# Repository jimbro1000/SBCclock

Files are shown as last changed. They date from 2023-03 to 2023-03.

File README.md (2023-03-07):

# Clock Card for HD6309SBC #

This board provides a variety of divided clock signals
to the 6809SBC board.

Where the SBC board calls for a quadrature clock (for
the 6809E variants) the board also provides Q and E.

The design is intended to be swappable to permit
easy exchange of different clock rates or different
clock generator designs.

The intended target is a raw clock of 25.175MHz to
facilitate a VGA signal. The CPU then operates at
one eighth of that - 3.15MHz, slightly above the
expected clock maximum for a C-class processor but
well within tolerance.

By having a swappable clock card the target 
operating frequency can be halved again to allow
the use of B-class processors while retaining
the 25MHz VGA signal. Again this is slightly
above specification at 1.57MHz but within the
tolerance of the design.

## Outputs ##

The card must provide the raw clock on Clock24, this
can be any frequency (that the CPUs support) but 
changing from the VGA clock frequency will require a
different approach to video output.

Outputs are then expected for the clock divided by
2, 4, 8 and 16 (Clock12, Clock6, Clock3 and Clock1.5)

Where Q and E are used they are output along with the
inverse of each.

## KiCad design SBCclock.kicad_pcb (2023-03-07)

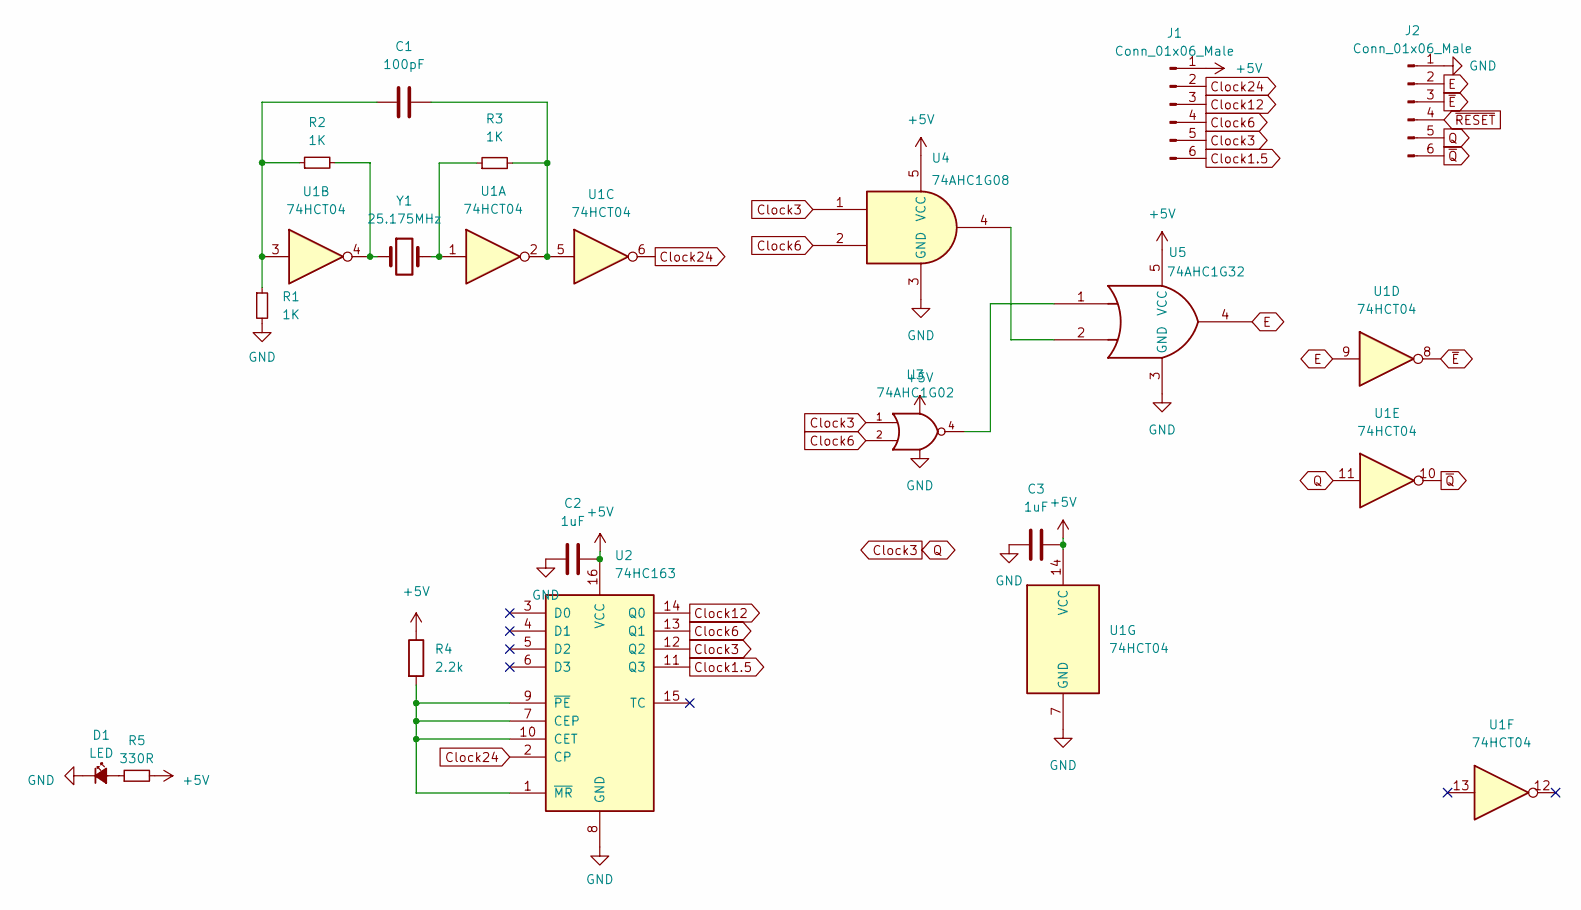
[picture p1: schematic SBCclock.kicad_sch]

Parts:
C1: 100pF; C_0805_2012Metric_Pad1.18x1.45mm_HandSolder; DigiKey 4363-0805N180FW251XCT-ND
C2, C3: 1uF; C_0805_2012Metric_Pad1.18x1.45mm_HandSolder; DigiKey 4363-0805N180FW251XCT-ND
D1: LED; LED_0805_2012Metric_Pad1.15x1.40mm_HandSolder
J1, J2: Conn_01x06_Male; PinHeader_1x06_P2.54mm_Vertical
R1, R2, R3: 1K; R_0805_2012Metric_Pad1.20x1.40mm_HandSolder
R4: 2.2k; R_0805_2012Metric_Pad1.20x1.40mm_HandSolder; DigiKey 2019-RK73H2ATTD2201FCT-ND
R5: 330R; R_0805_2012Metric_Pad1.20x1.40mm_HandSolder
U1: 74HCT04; SOIC-14_3.9x8.7mm_P1.27mm
U2: 74HC163; SOIC-16_3.9x9.9mm_P1.27mm; DigiKey 296-SN74HC163DTCT-ND
U3: 74AHC1G02; SOT-353_SC-70-5_Handsoldering
U4: 74AHC1G08; SOT-353_SC-70-5_Handsoldering
U5: 74AHC1G32; SOT-353_SC-70-5_Handsoldering
Y1: 25.175MHz; Crystal_SMD_HC49-SD; DigiKey 300-6149-1-ND

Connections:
+5V: C2.1, C3.1, J1.1, R4.1, R5.2, U1.14 (VCC), U2.16 (VCC), U3.5 (VCC), U4.5 (VCC), U5.5 (VCC)
Clock1.5: J1.6, U2.11 (Q3)
Clock3: J1.5, J2.5, U1.11, U2.12 (Q2), U3.1, U4.1
Clock6: J1.4, U2.13 (Q1), U3.2, U4.2
Clock12: J1.3, U2.14 (Q0)
Clock24: J1.2, U1.6, U2.2 (CP)
E: J2.2, U1.9, U5.4
GND: C2.2, C3.2, D1.1 (K), J2.1, R1.2, U1.7 (GND), U2.8 (GND), U3.3 (GND), U4.3 (GND), U5.3 (GND)
unnamed: C1.1, R3.2, U1.2, U1.5
unnamed: C1.2, R1.1, R2.1, U1.3
unnamed: D1.2 (A), R5.1
unnamed: R2.2, U1.4, Y1.1
unnamed: R3.1, U1.1, Y1.2
unnamed: R4.2, U2.1 (~MR), U2.7 (CEP), U2.9 (~PE), U2.10 (CET)
unnamed: U3.4, U5.1
unnamed: U4.4, U5.2
~E: J2.3, U1.8
~Q: J2.6, U1.10
~RESET: J2.4

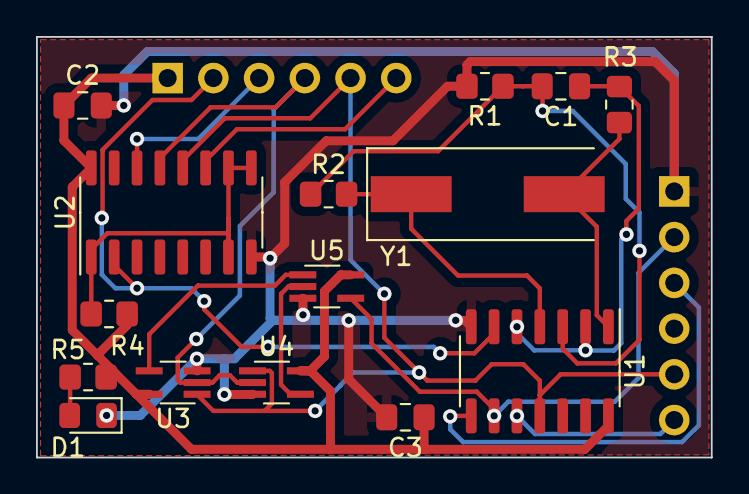
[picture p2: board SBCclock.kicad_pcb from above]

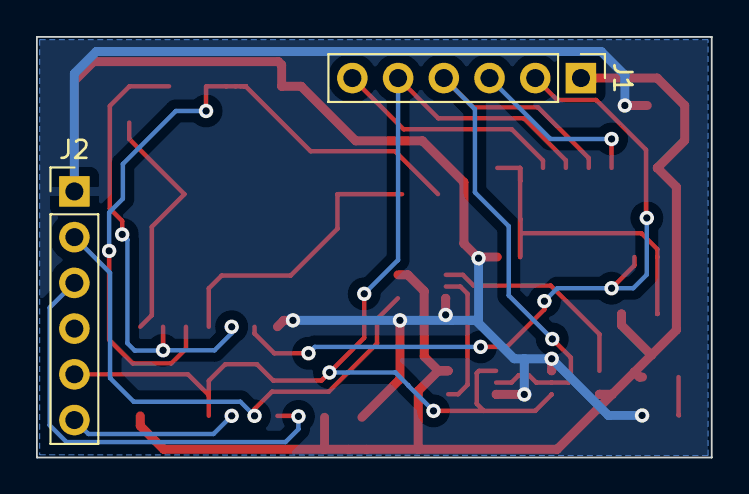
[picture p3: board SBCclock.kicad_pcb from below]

Board: 2 copper layers, 37.5 x 23.4 mm, 17 parts (2 on the bottom side), 18 nets.

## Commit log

2023-02-16 chore: tweak values
    [SBCclock.kicad_pcb, SBCclock.kicad_sch]
2023-02-16 chore: adjust routing
    [SBCclock.kicad_pcb, SBCclock.kicad_sch]
2023-02-16 refine for build
    [SBCclock.kicad_pcb]
2023-03-07 revise E generation
    [SBCclock.kicad_pcb, SBCclock.kicad_sch]
